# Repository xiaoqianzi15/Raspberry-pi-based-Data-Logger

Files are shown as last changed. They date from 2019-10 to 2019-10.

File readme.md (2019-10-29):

Raspi based data-logger   //not finished
ref:    
place to find the definition of Pin at Raspi     https://pinout.xyz/

Final product
Hardware       
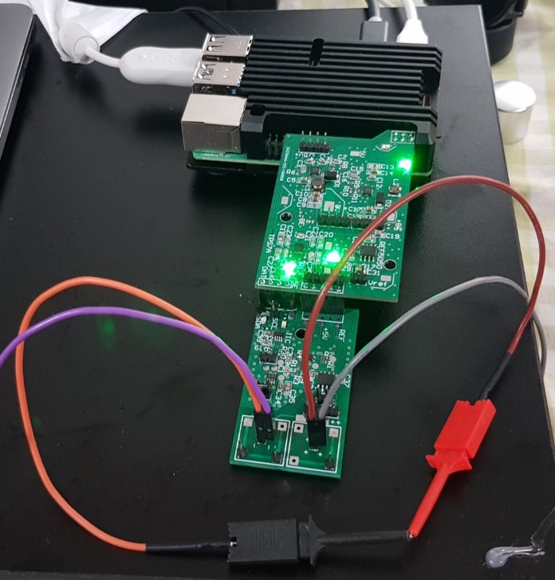
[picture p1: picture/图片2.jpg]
     
Software       
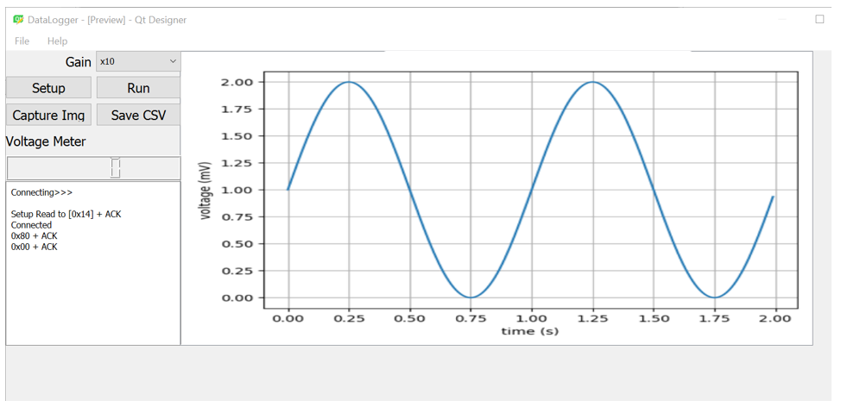
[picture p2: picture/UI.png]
     
Hardware schematic:
Power:      
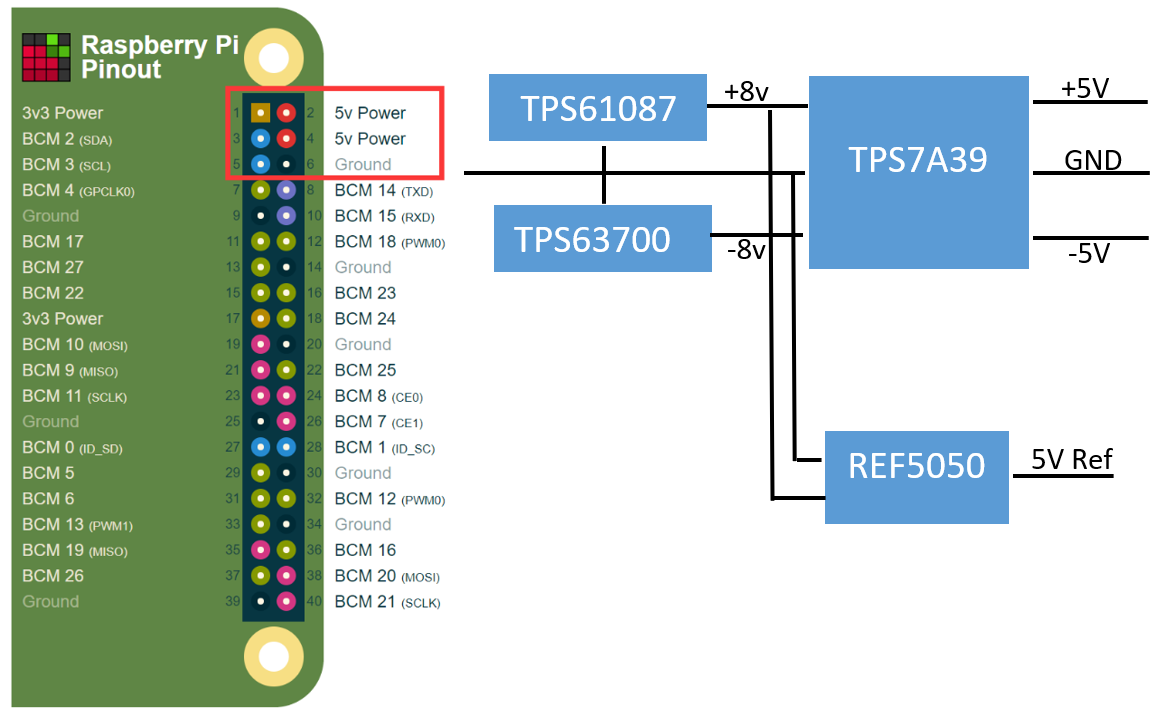
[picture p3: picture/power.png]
         

Front end:    
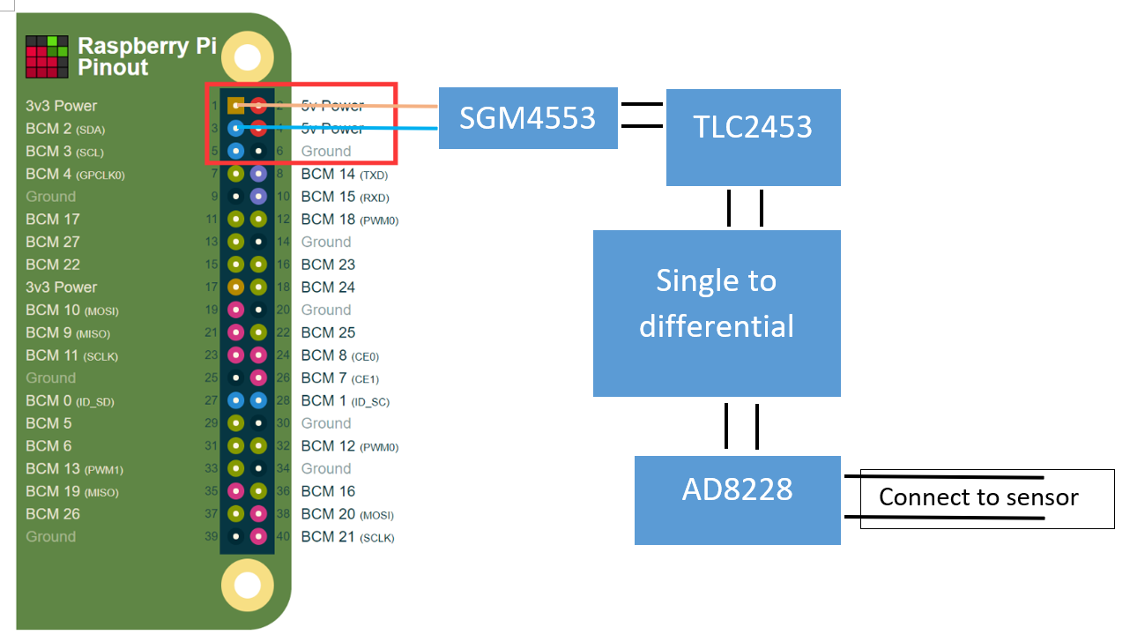
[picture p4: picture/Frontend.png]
             

Software:     
The software I'm using is:     
Smbus2:     
https://pypi.org/project/smbus2/    
The function I'm using is :i2c_rdwr     
I'm using this function is The ADC I'm using generate 2byte data. so the date go this way      
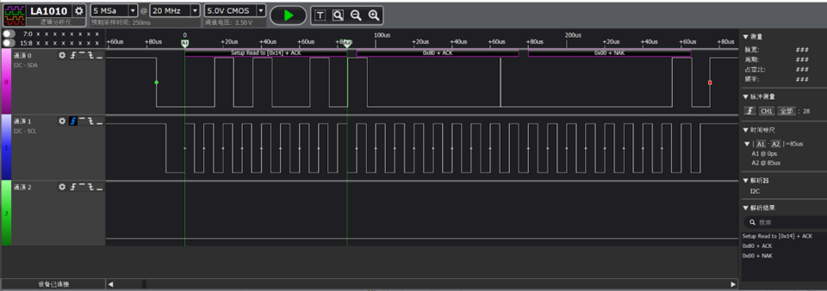
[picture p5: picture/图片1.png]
              
So  i2c_rdwr can get data from ADC and storage it in Raspi. And it is ready to be used for Qt and Matplot

Pyside2:
https://pypi.org/project/PySide2/
Why I'm using this is this is the based on Qt5 so it works so good in Raspi and it get official support from Raspi Group.
It is better than Tkinter. Tkinter is easier but the Example is not working.
All the Pyside2 examples are working good in Raspberry pi4 4G.

Matplotlib:

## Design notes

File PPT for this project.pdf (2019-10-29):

# Raspberry Pi based Data-logger

9 Oct 2019

SUPERVISOR: Professor Giacinta Parish Student Name: ZHU QIAN
Student number: 22113255

## Raspberry Pi based Data-Logger

# Introduction

## 1. Requirement 2. Hardware design

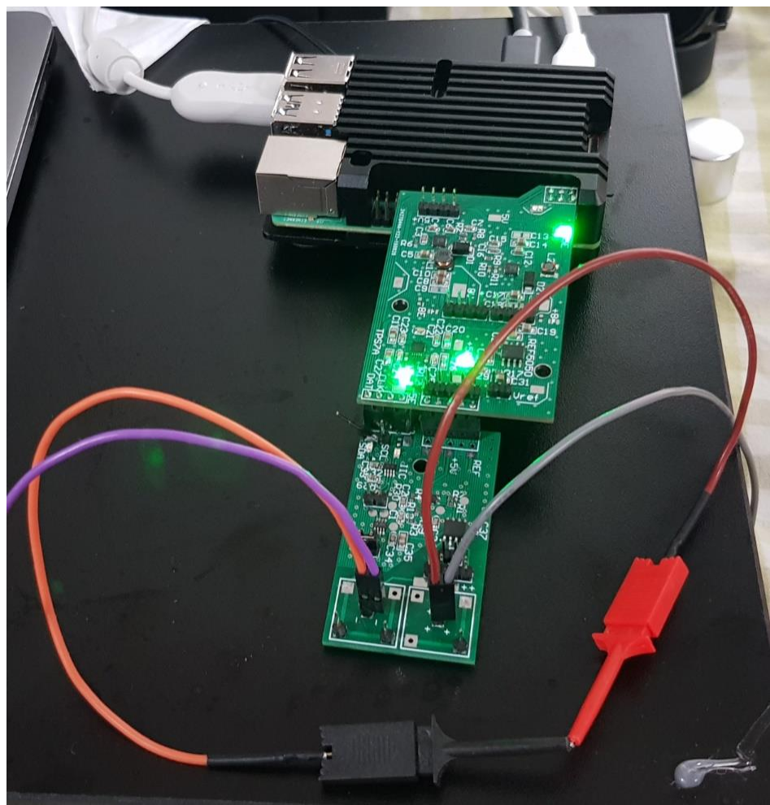
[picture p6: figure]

## - Power - Analog to Digital converter 3. Software design - Basic function - Human interface 4. Result 5. Conclusion

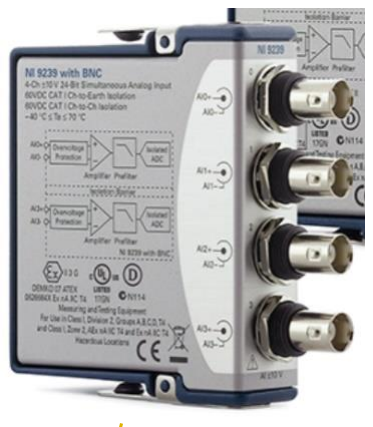
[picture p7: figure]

### Requirements – Part1

## Raspberry Pi based Data-Logger

Equipment using right now

Datalogger | NI 9239
USB Chassis | NI cDAQ -9171
Computer | Windows computer
Price>5000$ | Include software and hardware

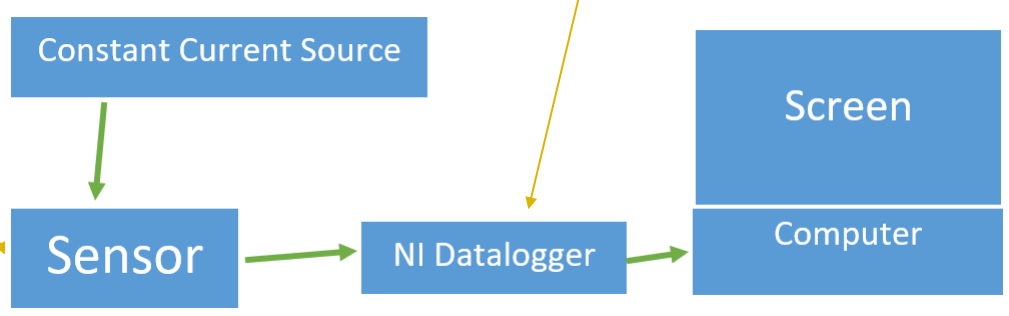
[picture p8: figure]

AlGaN/GaN Sensor
Device2 and Gate
area

## Raspberry Pi based Data-Logger

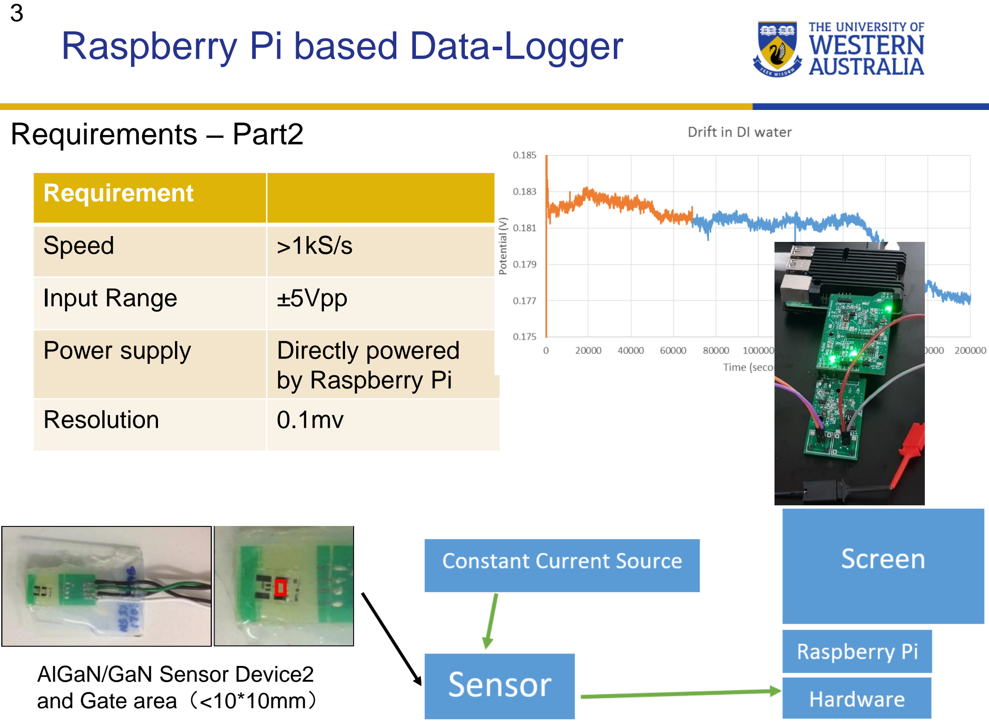
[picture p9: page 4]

### Requirements – Part2

Requirement

Speed | >1kS/s
Input Range | ±5Vpp
Power supply | Directly powered by Raspberry Pi
Resolution | 0.1mv

AlGaN/GaN Sensor Device2
and Gate area（<10*10mm）

## Raspberry Pi based Data-Logger

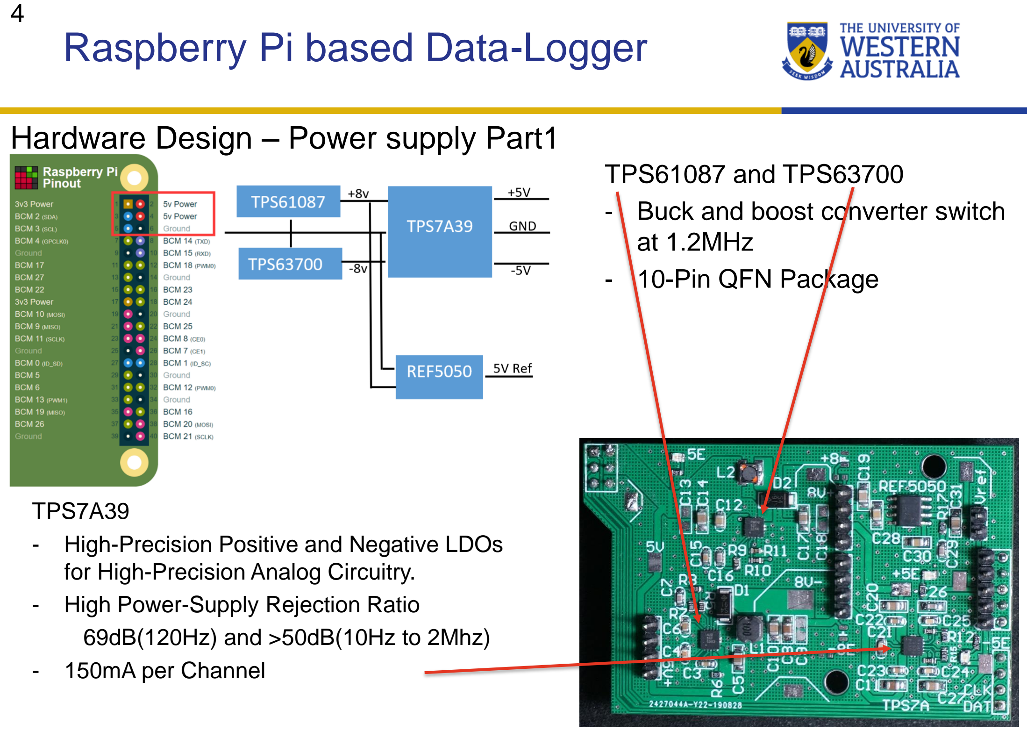
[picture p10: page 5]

### Hardware Design – Power supply Part1

TPS61087 and TPS63700
- Buck and boost converter switch at 1.2MHz
- 10-Pin QFN Package

TPS7A39
- High-Precision Positive and Negative LDOs for High-Precision Analog Circuitry.
- High Power-Supply Rejection Ratio 69dB(120Hz) and >50dB(10Hz to 2Mhz)
- 150mA per Channel

## Raspberry Pi based Data-Logger

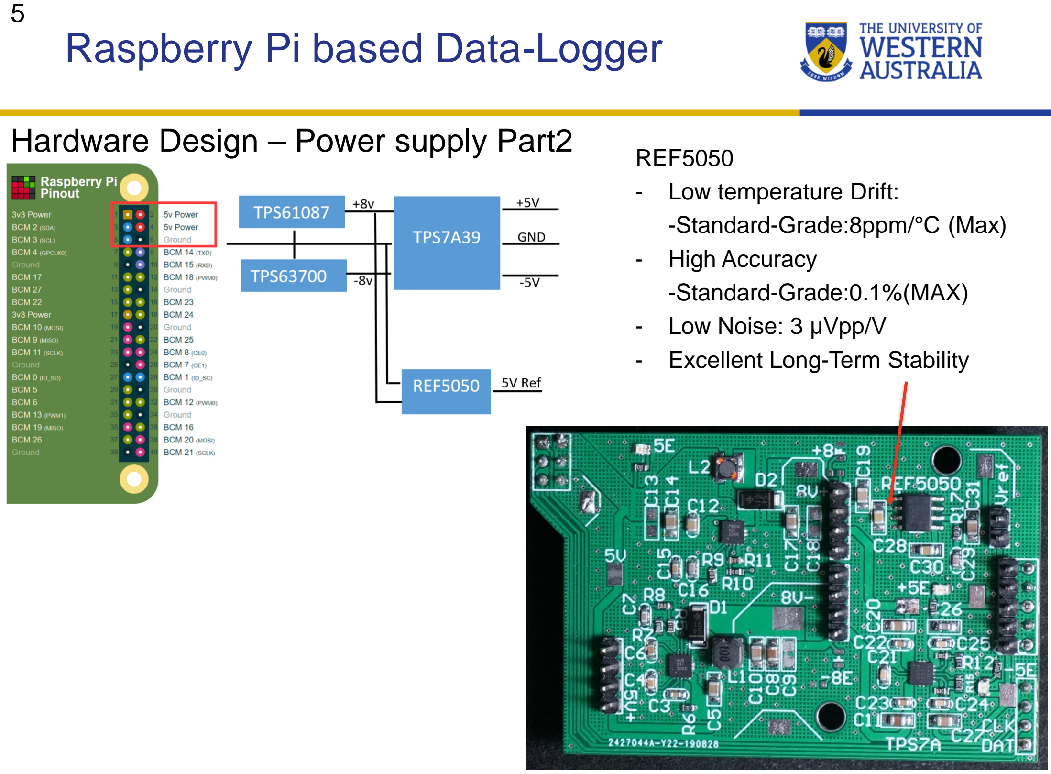
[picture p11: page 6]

### Hardware Design – Power supply Part2

REF5050
- Low temperature Drift:
-Standard-Grade:8ppm/°C (Max)
- High Accuracy
-Standard-Grade:0.1%(MAX)
- Low Noise: 3 μVpp/V
- Excellent Long-Term Stability

## Raspberry Pi based Data-Logger

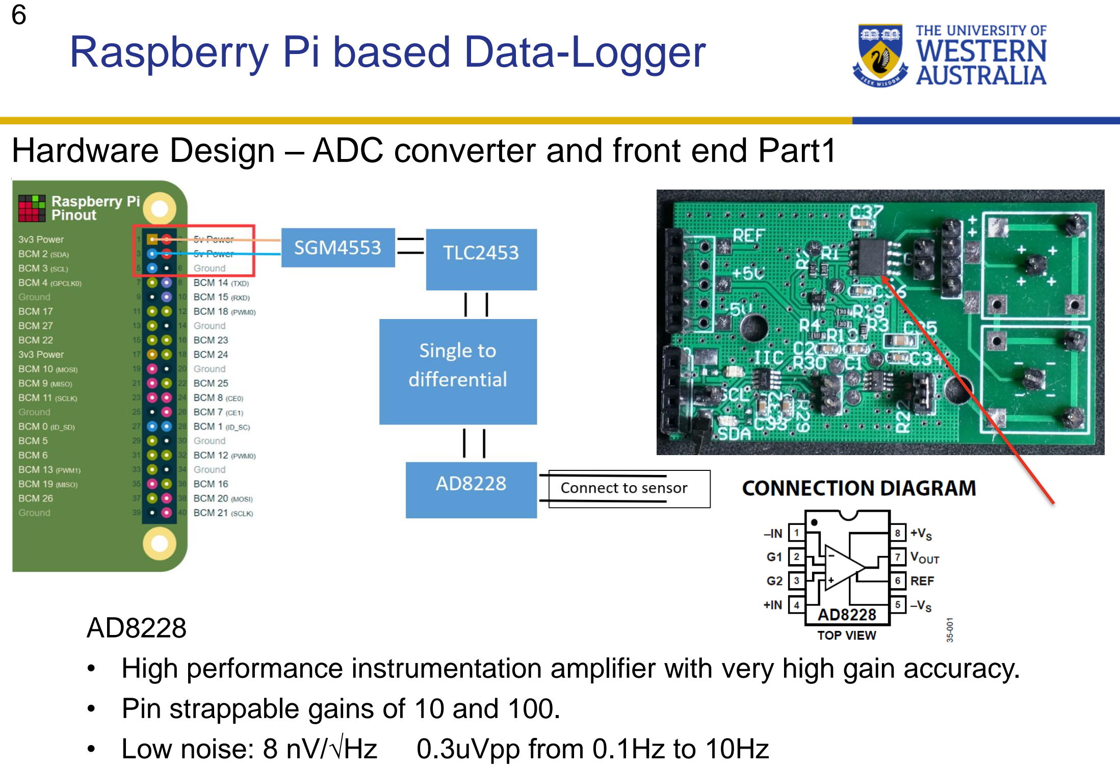
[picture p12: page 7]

### Hardware Design – ADC converter and front end Part1

AD8228
- High performance instrumentation amplifier with very high gain accuracy.
- Pin strappable gains of 10 and 100.
- Low noise: 8 nV/√Hz 0.3uVpp from 0.1Hz to 10Hz

### Hardware Design – ADC converter and front end Part2

## Raspberry Pi based Data-Logger

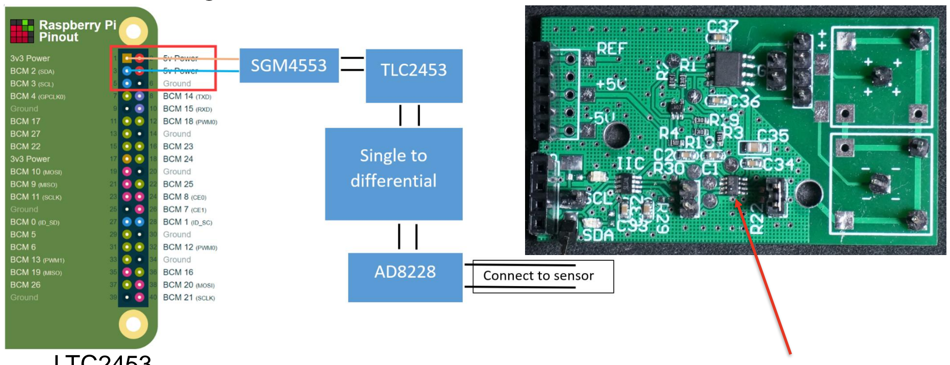
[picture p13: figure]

LTC2453
- 16Bit ΔΣ ADC with I2C interface
- 2LSB offset Error
- Differential input range
- 60 conversions Per Second

## Raspberry Pi based Data-Logger

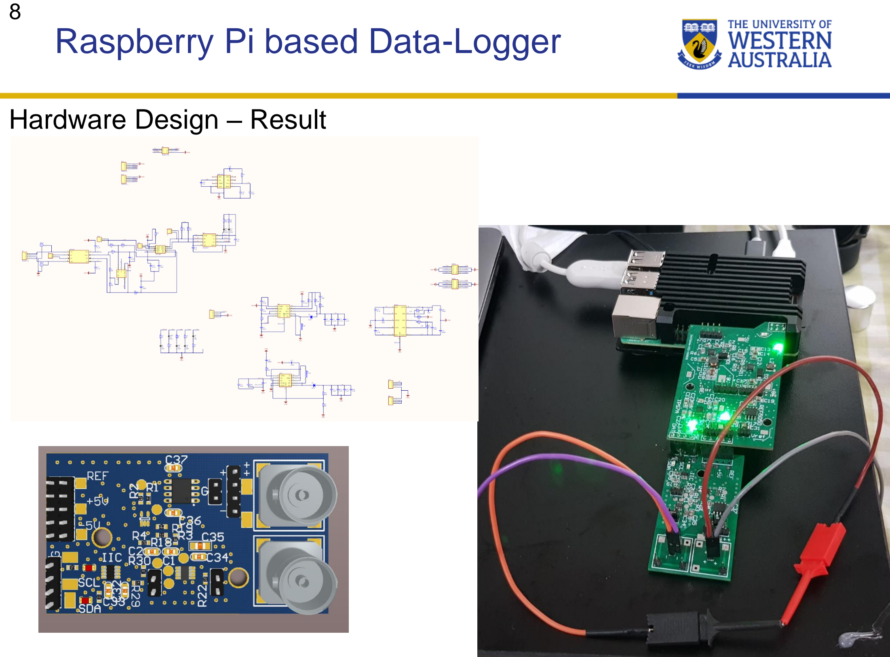
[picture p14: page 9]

### Hardware Design – Result

## Raspberry Pi based Data-Logger

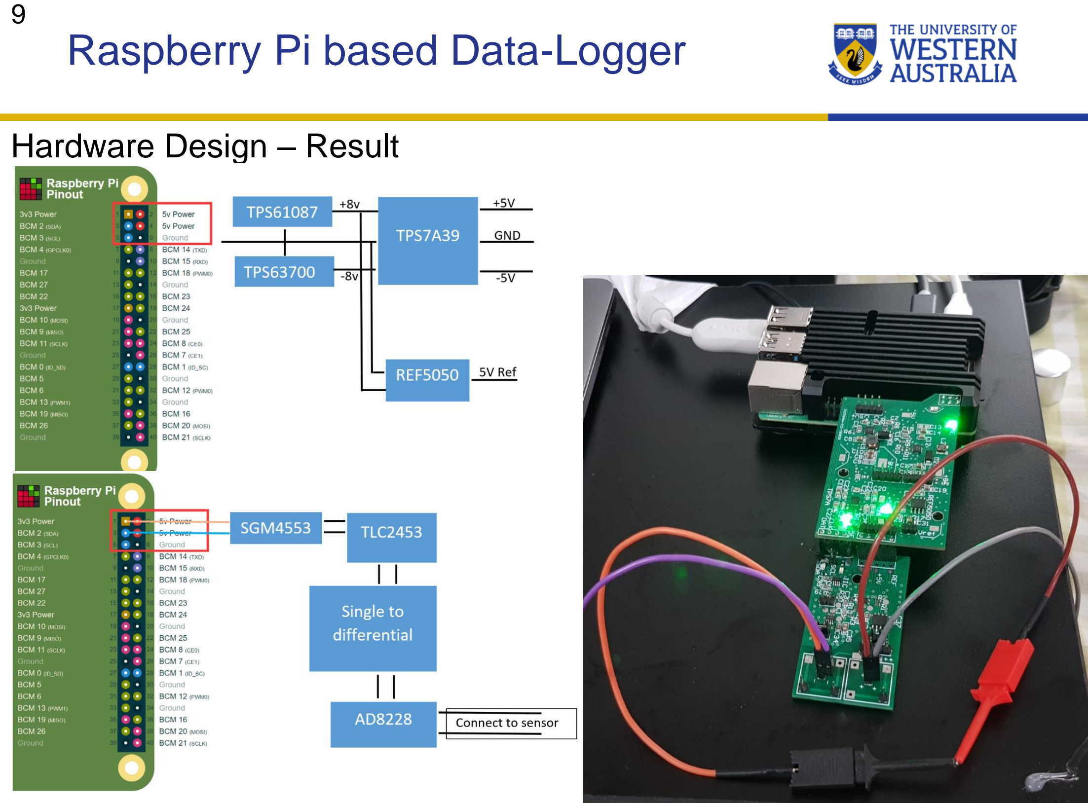
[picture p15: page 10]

### Hardware Design – Result

### Software Design

## Raspberry Pi based Data-Logger

- Smbus2
I2C interface to let Raspberry pi can easy to communicate with ADC
- QT PySide2 for Raspberry Pi
A official Python module from Qt for Python project. Which provide access to the complete Qt 5.12+ framework.
- Matplotlib for 2D plotting
A Python 2D plotting library which publication quality figures in Python scripts

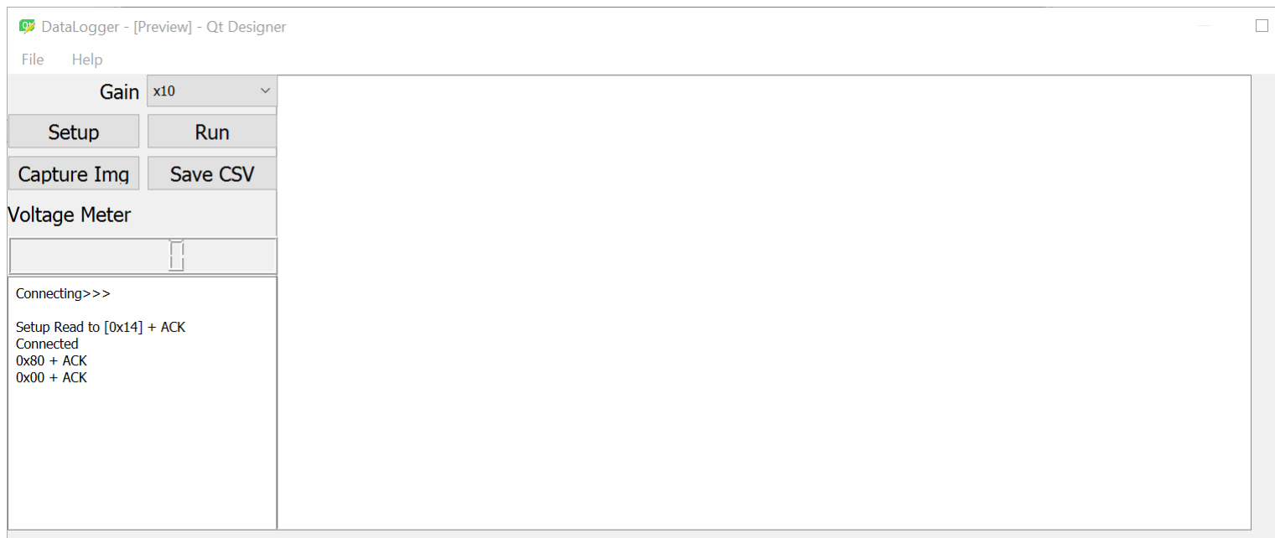
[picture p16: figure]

## Raspberry Pi based Data-Logger

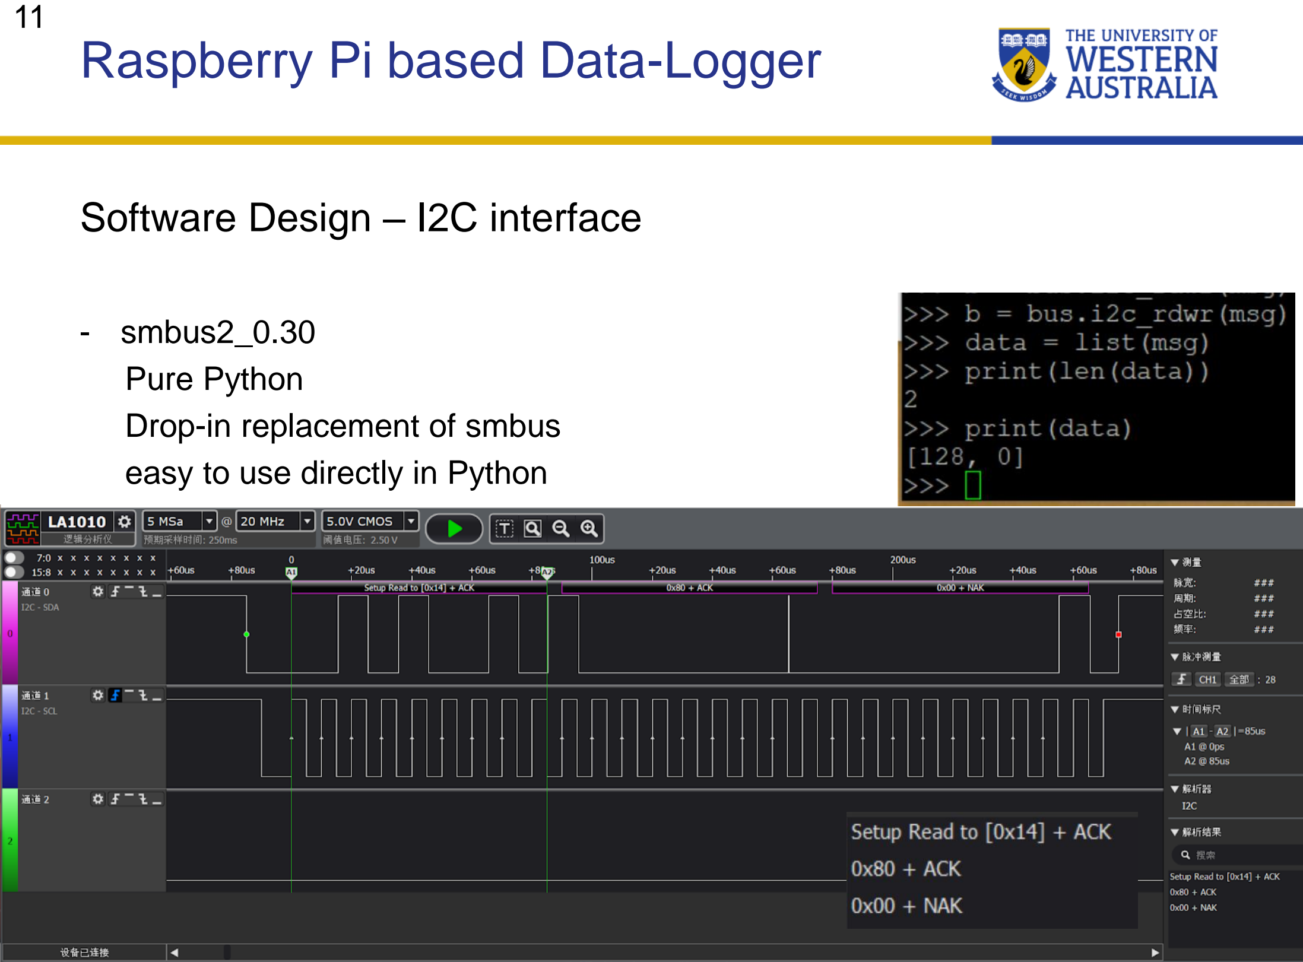
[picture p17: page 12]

### Software Design – I2C interface

- smbus2_0.30
Pure Python
Drop-in replacement of smbus easy to use directly in Python

## Raspberry Pi based Data-Logger

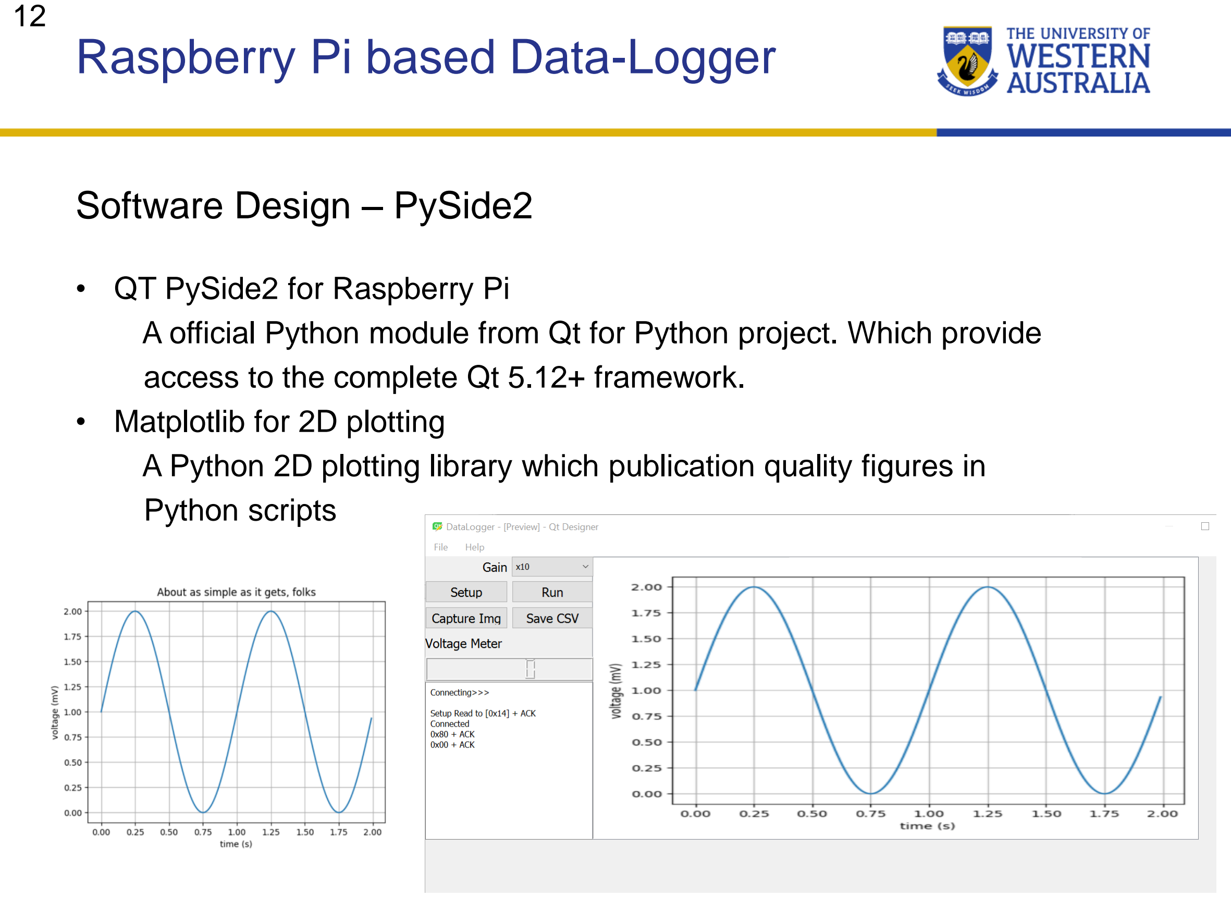
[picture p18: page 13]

### Software Design – PySide2

- QT PySide2 for Raspberry Pi
A official Python module from Qt for Python project. Which provide access to the complete Qt 5.12+ framework.
- Matplotlib for 2D plotting
A Python 2D plotting library which publication quality figures in Python scripts

### Result - Price

## Raspberry Pi based Data-Logger

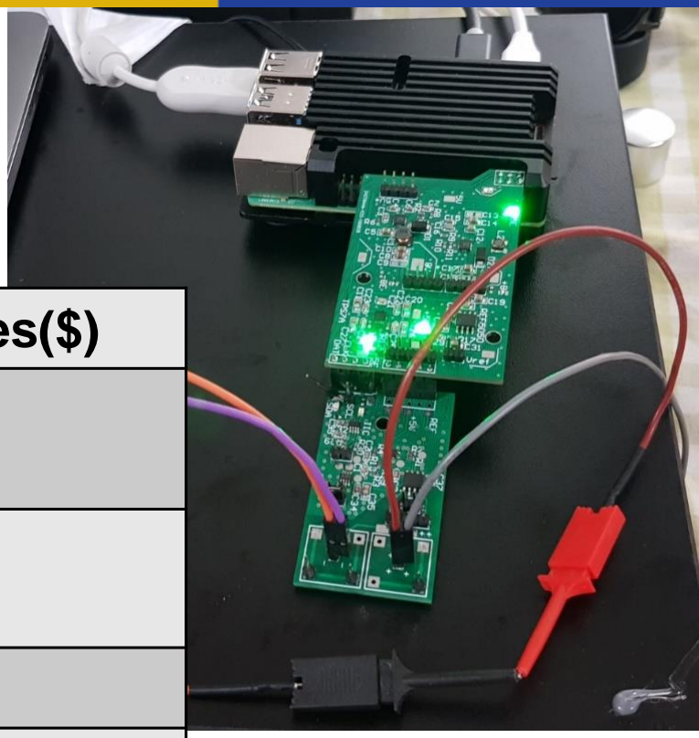
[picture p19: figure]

| | Prices($)
Single Board Computer | Raspberry Pi4 2G RAM | 60
Analog to Digital Converter | LT2453 16Bit | 4.87
AMP | AD8228 | 7.9
Voltage reference | REF5050 | 4
DCDC Boost | TPS63700 | 2
DCDC Boost | TPS61087 | 2
High precise linear regulator | TPS7A39 | 6
PCB | 5pcs PCB | 3
Total | | 89.77

### Conclusion - Future work - Protection

### - Isolate power supply

## Raspberry Pi based Data-Logger

# Thank you for listening

## Raspberry Pi based Data-Logger

Also thanks for Brett, Gilberto and Jeremy helps me a lot of this project

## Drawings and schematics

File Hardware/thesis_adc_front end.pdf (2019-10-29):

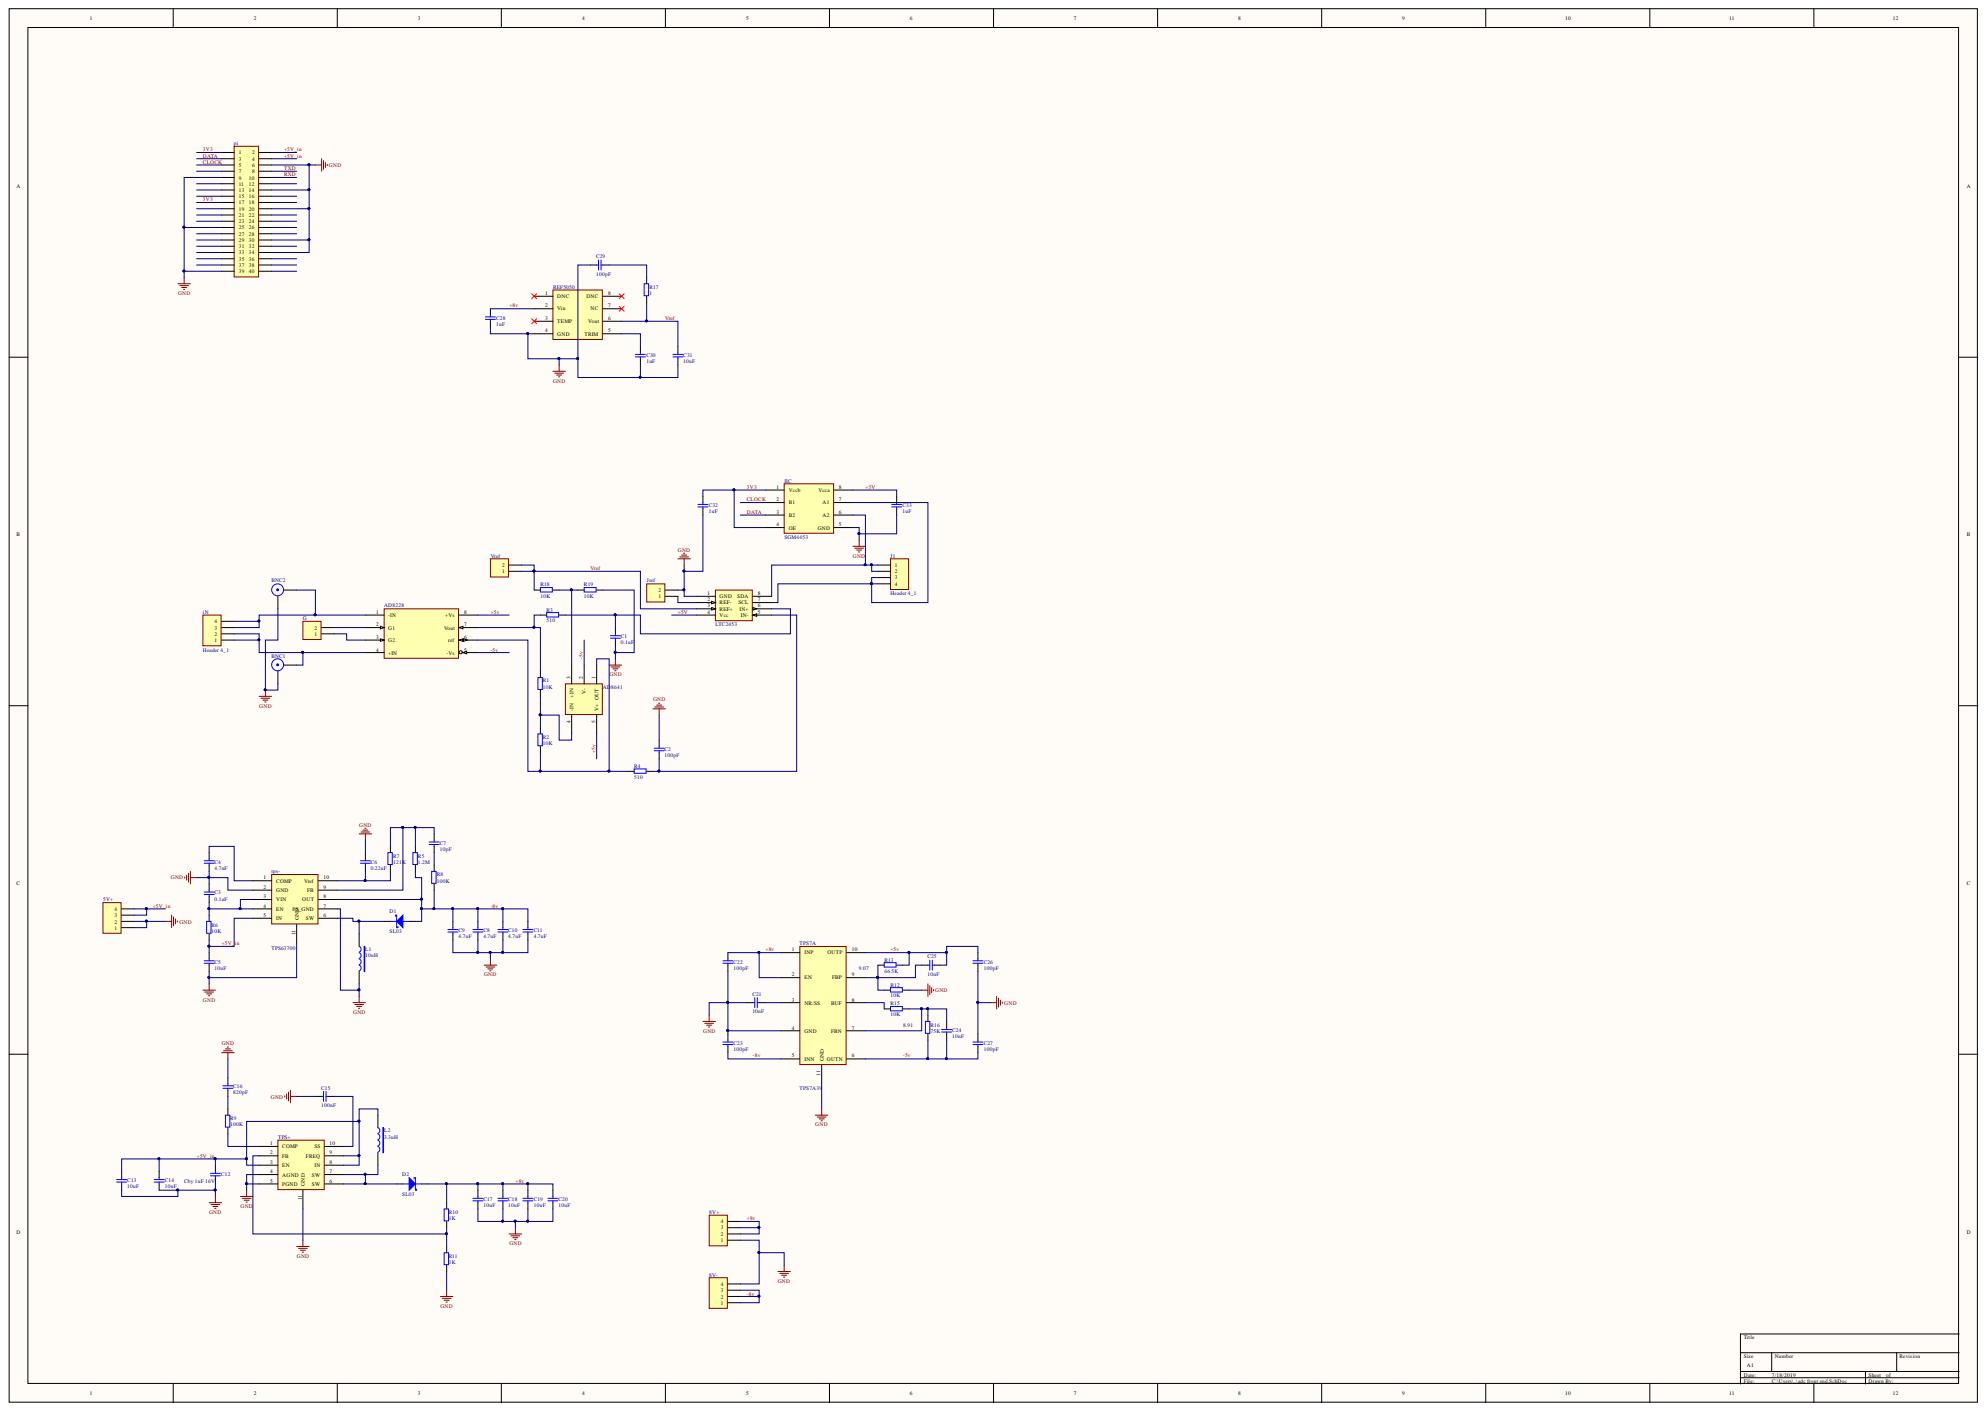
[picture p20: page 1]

DNC 1 | NC Vout

Vin 2 | 7

TEMP 3 | 6

3 4 2 1 | G 2 1 | -IN 1 G1 2 ref | 0.1uF C1 | +5V | LTC2453

COMP 1 FB 2

EN 3 IN SW | 8
AGND 4 | 7
